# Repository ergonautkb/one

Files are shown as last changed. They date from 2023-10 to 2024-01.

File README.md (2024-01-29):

# Ergonaut One

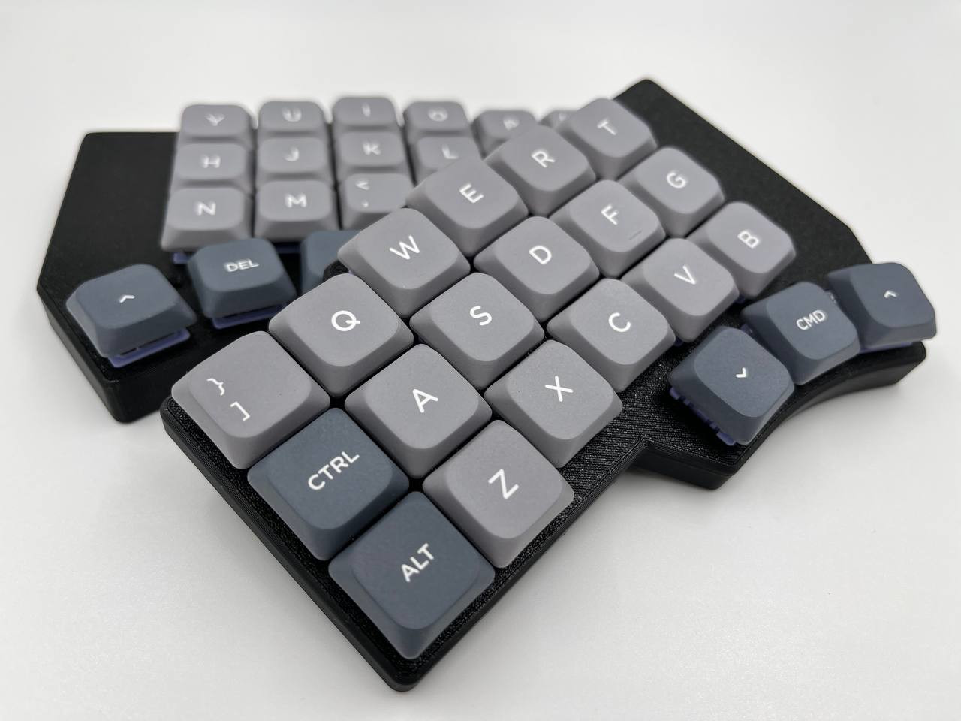
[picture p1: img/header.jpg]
Ergonaut One Header Image

*Ergonaut One in Modern Case*

Ergonaut One is an open-source ergonomic wireless split mechanical keyboard designed by Ergonaut Keyboards.

Inspiration for the keyboard was taken from these projects:

* [Corne](https://github.com/foostan/crkbd) by [foostan](https://github.com/foostan)
* [Dao](https://github.com/yumagulovrn/dao-choc-ble) by [yumagulovrn](https://github.com/yumagulovrn)

## Idea

We wanted to create a pretty affordable, nice looking, and, most importantly, very DIY-friendly ergonomic wireless split keyboard with Gateron Low Profile switches.

## Photos

Gallery can be found on [imgur](https://imgur.com/a/sOBBtmQ).

## Features

* Low-profile, which will reduce strain on your beautiful hands;
* Split. You can put the keyboard where it'll be comfortable exactly for you;
* Pretty long battery life. 250mAh battery gives up to a month of usage without charging;
* Wide availability and range of [compatible keycaps](https://ergonautkb.com/docs/switches/gateron-low-profile#keycaps-compatibility);
* Easily replaceable [switches](https://ergonautkb.com/docs/switches/gateron-low-profile#ks-33-v2) thanks to hot-swap sockets;
* Budget-friendly, because:
  * It uses relatively cheap and widely available [Seeed Studio XIAO nRF52840](https://wiki.seeedstudio.com/XIAO_BLE/) as MCU;
  * It uses one PCB design for both halves of the keyboard;
  * Everything except PCB's, components and hardware (screws, nuts) can be 3D printed.
* Beginner-friendly, because:
  * PCB is easy to solder;
  * Cases are easy to print.
* Wireless by design - no unnecessary wires, no unused connectors on the board;
* Free in terms of hardware design. It's licensed under permissive [CERN-OHL-P v2](https://ohwr.org/cern_ohl_p_v2.pdf) license, which means:
  * you are free to manufacture it yourself;
  * you are free to sell your manufactured hardware for profit.

## Build Guide

BOM and Build Guide can be found in [Ergonaut Keyboards Documentation Portal](https://ergonautkb.com/docs/keyboards/ergonaut-one/intro).

## Firmware

Firmware can be found in [one-zmk-config](https://github.com/ergonautkb/one-zmk-config) repository.

## Gerbers

| Front | Back |
| --- | --- |
| front | back |

* [Gerbers for JLCPCB](../../releases/latest/download/pcb-JLCPCB_gerbers.zip)
* [Gerbers for PCBWay](../../releases/latest/download/pcb-PCBWay_gerbers.zip)

## Community projects

### Accessories

* [Frames for Magic Trackpad 2/3 and Laptops](https://www.thingiverse.com/thing:6447743) by [Alex Kh](https://www.thingiverse.com/alehano777/designs)

## Contacts

* Documentation portal: https://ergonautkb.com
* Telegram: https://ergonautkb.t.me
* Telegram (ru): https://ergonautkb_ru.t.me

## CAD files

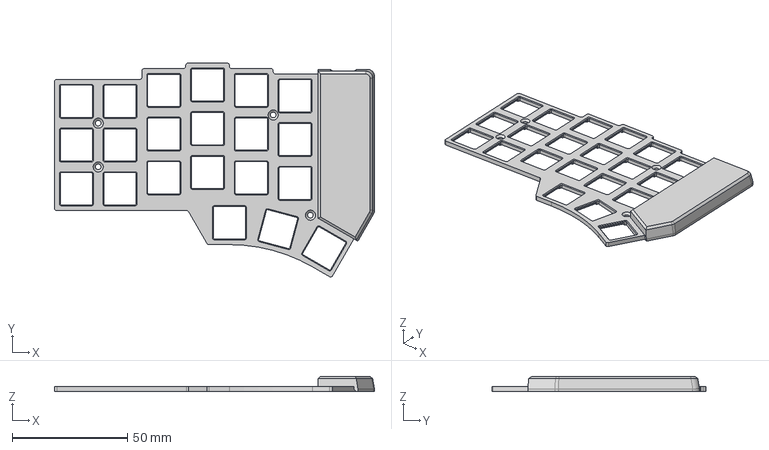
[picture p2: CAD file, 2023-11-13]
cases/3d/classic/step/top.step
139.0 x 92.9 x 6.70 mm

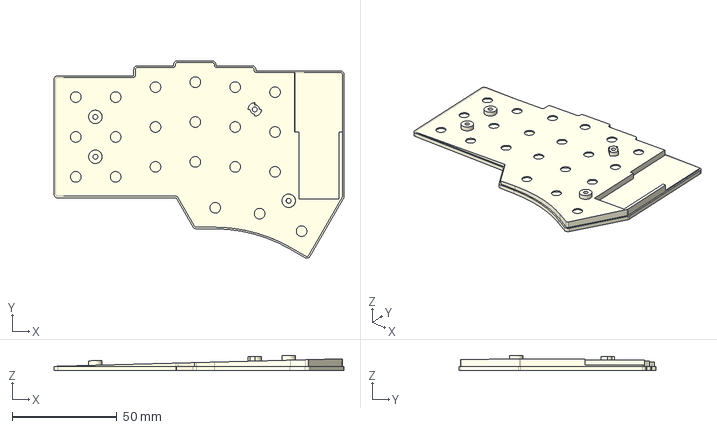
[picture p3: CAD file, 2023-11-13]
cases/3d/modern/step/bottom.step
138.2 x 94.1 x 7.25 mm

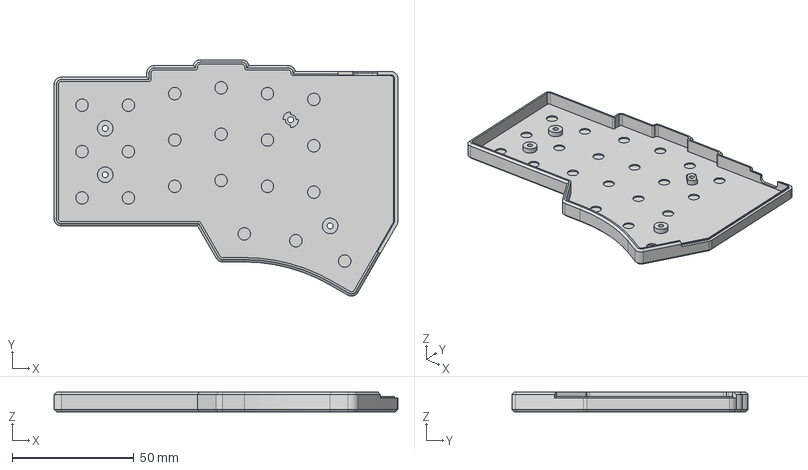
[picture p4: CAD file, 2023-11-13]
cases/3d/classic/step/bottom.step
141.0 x 96.9 x 8.00 mm

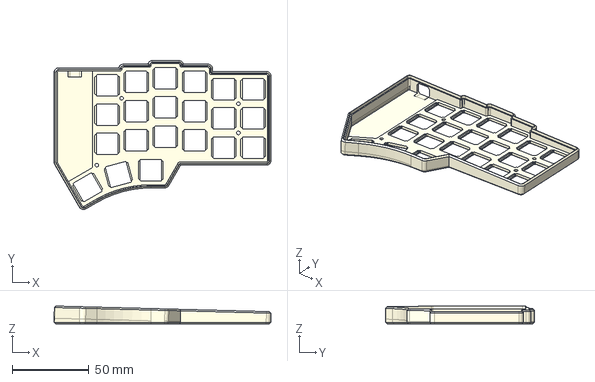
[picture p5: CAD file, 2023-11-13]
cases/3d/modern/step/top.step
141.2 x 96.9 x 11.7 mm

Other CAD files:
cases/3d/classic/bottom.step
cases/3d/classic/stl/bottom.stl
cases/3d/classic/stl/top.stl
cases/3d/modern/stl/bottom.stl
cases/3d/modern/stl/top.stl

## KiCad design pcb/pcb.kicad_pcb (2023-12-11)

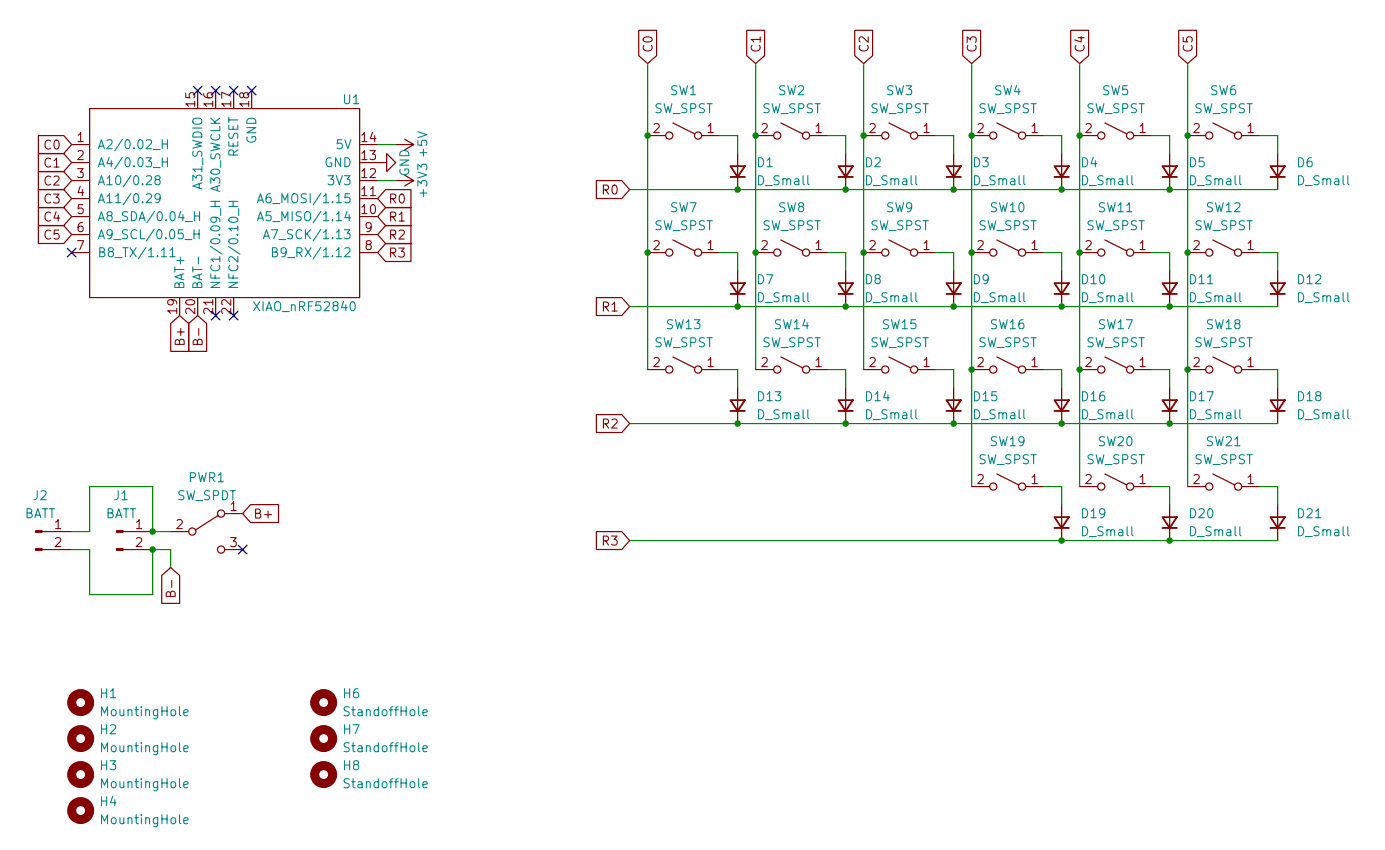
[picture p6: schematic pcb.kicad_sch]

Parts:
D1, D2, D3, D4, D5, D6, D7, D8, D9, D10, D11, D12, D13, D14, D15, D16, D17, D18, D19, D20, D21: D_Small; Diode_TH_SMD_DUAL
H1, H2, H3, H4: MountingHole; Hole_4.2mm
H6, H7, H8: StandoffHole; Hole_2.2mm
J1: BATT; Battery
J2: BATT; JST_SH_Battery_DUAL
PWR1: SW_SPDT; MSK-12C02_DUAL
SW1, SW2, SW3, SW4, SW5, SW6, SW7, SW8, SW9, SW10, SW11, SW12, SW13, SW14, SW15, SW16, SW17, SW18, SW19, SW20, SW21: SW_SPST; KS-27_KS-33_Hotswap_1U_DUAL
U1: XIAO_nRF52840; XIAO_nRF52840_DUAL

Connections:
+3V3: U1.12 (3V3)
+5V: U1.14 (5V)
B+: PWR1.1 (A), U1.19 (BAT+)
B-: J1.2, J2.2, U1.20 (BAT-)
C0: SW1.2 (B), SW7.2 (B), SW13.2 (B), U1.1 (A2/0.02_H)
C1: SW2.2 (B), SW8.2 (B), SW14.2 (B), U1.2 (A4/0.03_H)
C2: SW3.2 (B), SW9.2 (B), SW15.2 (B), U1.3 (A10/0.28)
C3: SW4.2 (B), SW10.2 (B), SW16.2 (B), SW19.2 (B), U1.4 (A11/0.29)
C4: SW5.2 (B), SW11.2 (B), SW17.2 (B), SW20.2 (B), U1.5 (A8_SDA/0.04_H)
C5: SW6.2 (B), SW12.2 (B), SW18.2 (B), SW21.2 (B), U1.6 (A9_SCL/0.05_H)
GND: U1.13 (GND)
unnamed: D1.2 (A), SW1.1 (A)
unnamed: D2.2 (A), SW2.1 (A)
unnamed: D3.2 (A), SW3.1 (A)
unnamed: D4.2 (A), SW4.1 (A)
unnamed: D5.2 (A), SW5.1 (A)
unnamed: D6.2 (A), SW6.1 (A)
unnamed: D7.2 (A), SW7.1 (A)
unnamed: D8.2 (A), SW8.1 (A)
unnamed: D9.2 (A), SW9.1 (A)
unnamed: D10.2 (A), SW10.1 (A)
unnamed: D11.2 (A), SW11.1 (A)
unnamed: D12.2 (A), SW12.1 (A)
unnamed: D13.2 (A), SW13.1 (A)
unnamed: D14.2 (A), SW14.1 (A)
unnamed: D15.2 (A), SW15.1 (A)
unnamed: D16.2 (A), SW16.1 (A)
unnamed: D17.2 (A), SW17.1 (A)
unnamed: D18.2 (A), SW18.1 (A)
unnamed: D19.2 (A), SW19.1 (A)
unnamed: D20.2 (A), SW20.1 (A)
unnamed: D21.2 (A), SW21.1 (A)
unnamed: J1.1, J2.1, PWR1.2 (B)
R0: D1.1 (K), D2.1 (K), D3.1 (K), D4.1 (K), D5.1 (K), D6.1 (K), U1.11 (A6_MOSI/1.15)
R1: D7.1 (K), D8.1 (K), D9.1 (K), D10.1 (K), D11.1 (K), D12.1 (K), U1.10 (A5_MISO/1.14)
R2: D13.1 (K), D14.1 (K), D15.1 (K), D16.1 (K), D17.1 (K), D18.1 (K), U1.9 (A7_SCK/1.13)
R3: D19.1 (K), D20.1 (K), D21.1 (K), U1.8 (B9_RX/1.12)

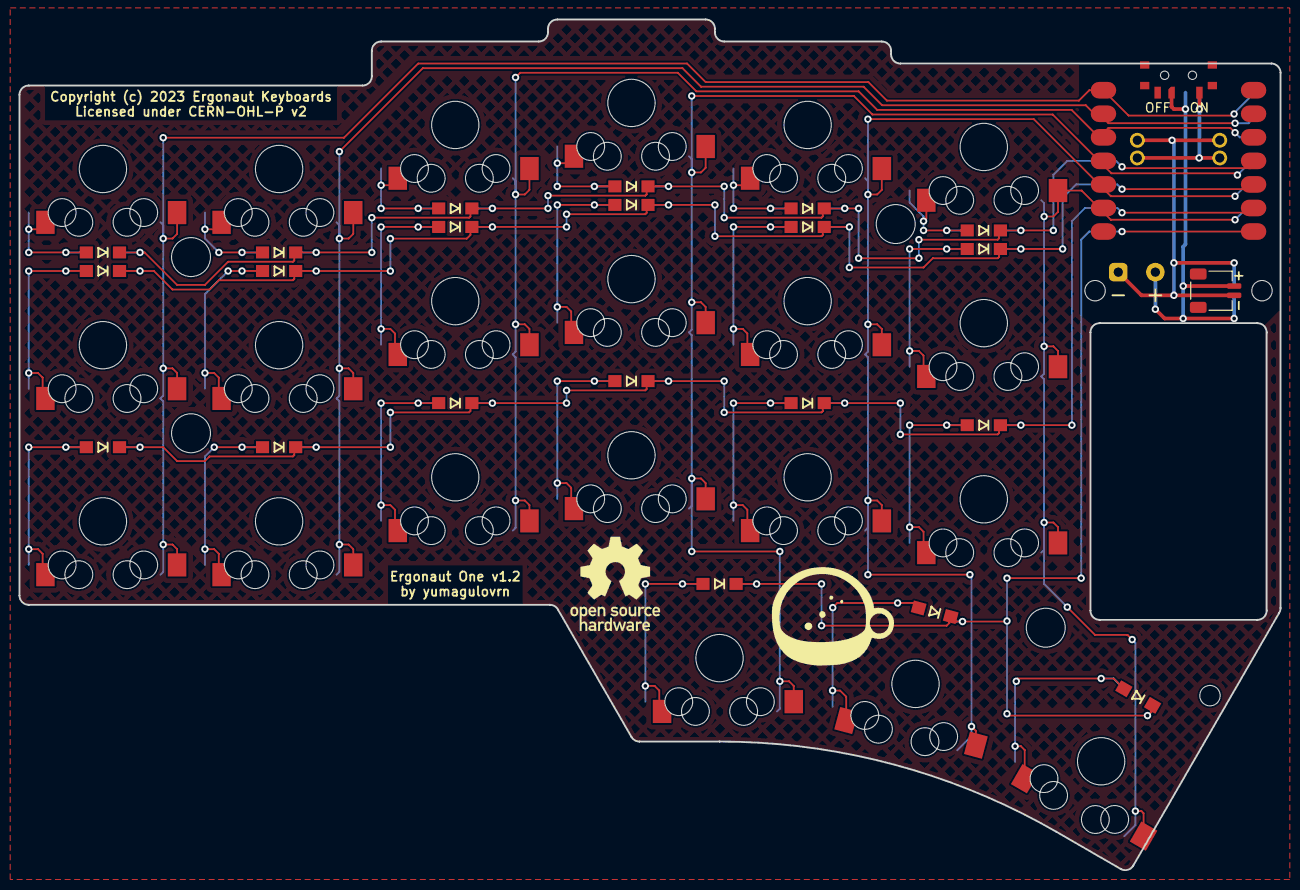
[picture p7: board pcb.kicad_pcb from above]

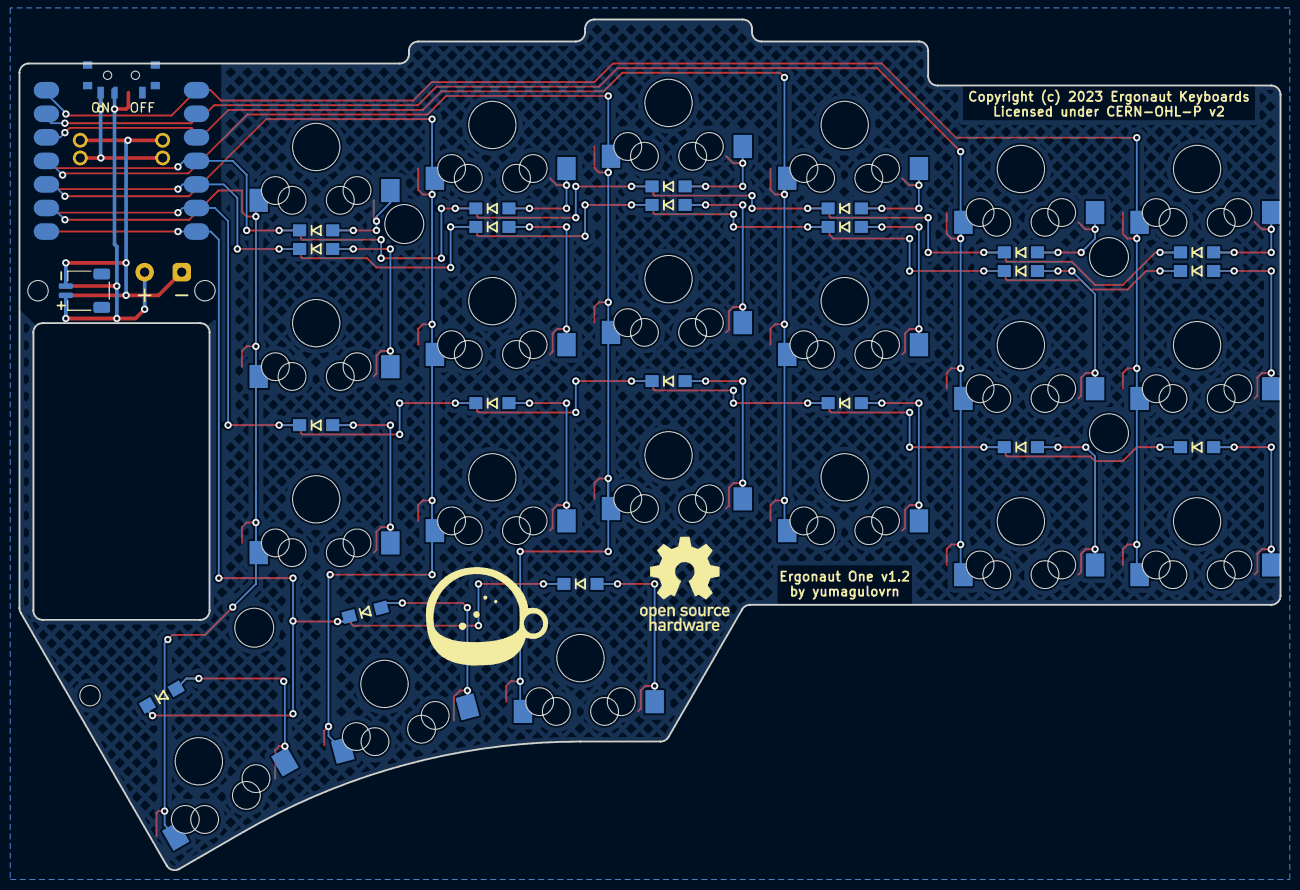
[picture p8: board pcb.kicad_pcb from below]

Board: 2 copper layers, 136.0 x 91.7 mm, 53 parts (22 on the bottom side), 34 nets.

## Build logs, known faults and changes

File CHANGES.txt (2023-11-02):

2023.11.01 - Initial release of version 1.0
2023.11.02 - Release of version 1.1. Changes: power switch silkscreen fix, diodes footprint fix, logo addition

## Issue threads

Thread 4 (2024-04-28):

Mirror x axis is not an option at JLC3DP

ctranstrum, 2024-04-28:
Sent the Ergonaut One classic case stl files to JLC 3D print service with a note to mirror the x axis for the second copy, and they responded that they can only print the file as-is. It would be nice to have the correct files available.

(By the way, I love this project! Is the Ergonaut One S going to be available soon? And are you planning a six column version of it?)

Michieljoris, 2024-07-15:
Plus one for the Ergonaut One S. The link in the docs to the repo is dead. Was it ever there?

kaiiiiiiiii, 2024-08-19:
Download Cura or any other slicer software. Open one of the stl files. Mirror on the x axis and export as stl again. Do the same for the other part.

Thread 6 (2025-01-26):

Addition of "vias" into footprints

yuki, 2025-01-26:
Hello!

First of all thanks for making this great project Open Source. This is not an issue "as itself", just a question.

I'm new into Kicad, and the split-custom-mechanichal-keyboards world, so maybe what I'm asking is not a good idea.

I'm interested in creating something like One with few modifications (add RGBs, and maybe cuttable one of the columns). I'm watching the KS-27_KS-33_HotSwap-1U_DUAL and I was thinking the possibility to add a "through hole" between each pad. This hole must have:
-
- F. paste
- B.paste
- 0.5mm diameter (I don't know if there's an option to create something like a "via" without a hole).

With this idea, there's a "via" in the footprint itself, instead of doing it in the PCB Editor. Something [like this](https://imgur.com/a/Mqrm4at)  .  With this, the number of vias in the PCB should be less than in One's, and the addition of tracks should be easier. What do you think?

The same idea could be used in the Diode_TH_SMD_DUAL footprint. Right now, each diode has a via in its side, which in the PCB must be connected with a track in front's pad and back's pad. With the "through hole" in the footprint will be easier to make the tracks, won't be?

I know that maybe this is not the forum to ask this, but for sure you have more knowledge about this that I have.

Thanks!

yuki, 2025-01-27:
I have asked in the Kicad Forum and it seems a good idea. https://forum.kicad.info/t/adding-vias-in-footprints/57916/9

yuki, 2025-01-28:
I have forked the project and changed the footprints.

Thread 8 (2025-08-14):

Clarification on Hot Swap Socket Model

addisonjones3, 2025-08-14:
In the [BOM](https://github.com/ergonautkb/ergonautkb.github.io/blob/main/docs/keyboards/ergonaut-one/build-preparations.md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) section of the documentation, it states to use KS-27 sockets. I just wanted to confirm those sockets are correct/compatible with the KS-33 Gateron switches stated earlier in the documentation.

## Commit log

2023-06-27 fix plate
    [plate.kicad_pcb]
2023-07-26 new rev
    [bottom.kicad_pcb, bottom.kicad_sch, pcb.kicad_sch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]
2023-10-31 preparation for release
    [bottom.kicad_pcb, bottom.kicad_sch, bottom.step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]
2023-11-02 release 1.1
    [pcb.kicad_pcb]
2023-11-03 naming fixes
    [bottom.step, bottom.stl, pcb.kicad_pcb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]
2023-11-06 fix cases
    [bottom.step, bottom.stl, top.step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]
2023-11-13 add case fixes
    [bottom.step, bottom.stl, top.step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]
2023-11-14 Add IBOM file for PCB
2023-12-07 fix: fix outline fillets
    [pcb.kicad_pcb]
2023-12-10 feat: change fillet radius
    [pcb.kicad_pcb]
2023-12-10 feat: bump board version
    [pcb.kicad_pcb]

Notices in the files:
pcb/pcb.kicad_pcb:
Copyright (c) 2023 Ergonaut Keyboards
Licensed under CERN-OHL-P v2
